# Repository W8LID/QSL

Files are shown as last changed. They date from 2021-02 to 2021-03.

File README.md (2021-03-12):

# QSL
A PCB QSL card that can be used as a cross band repeater.

QSL_V3

Introduction

The PCB QSL is a spin on the QSL cards that amateur radio operatrors send to one another to confirm contacts they have made over the air. QSL cards resemble post cards but also have information detailing the contact(s) made between two amateur radio operators.  QSL cards are also similar to post cards in that they often have artwork that can represent where or who they came from.

While first trying out KiCad, I came up with the idea that a PCB would make an interesting card that represents my interests in radio, electronics and micro controllers. The PCB QSL has all of the standard features of a paper QSL with silkscreened fields to fill out with contact info. It is also an unpopulated PCB that can be assembled into a working crossband reapeater.

The main components are an Atmel ATMEGA328 and Doji DRA818 VHF and UHF modules. The ATMEGA328 handles the module I/O and serial communications to configure the modules. A small number of passive components are also required to get up and running.

The Circuit

The original version (black solder mask) can only be assembled into a crossband repeater. Later versions can be used as a repeater, the default configuration, or as a dual band 2m, 70cm FM transceiver. In either configuration the goal was to use the minimum number of components as possible. 

In crossband, the audio out and in from each Dorji module are cross connected. This provides a simple voice repeating functionality. 

I/O control for the modules allows for monitoring the squelch status and can key the PTT of an opposing module. The enabling (PD) and the high and low power level of the modules can be handled by the MCU.

While attempting to keep component count to a minimum, it was decided to use the intrnal oscillator on the ATMEGA328. There are no critical timing needs that require the need for an external oscillator. 

Provisions are made for adding headers for ICSP and FTDI programmers to flash a bootloader and program using the Arduino IDE as if it were any other Arduino dev board.

The RF output of the modules are fed to a low pass filter before ending up at u.FL connectors. 

The dual band transceiver option is currently considered experimental and should be treated as such, feel free to offer feedback.

Programming

I have started sending out cards that are already populated with the MCU and the minimum passives required to make a crossband reapeater, the only components required are the DRA818 V and U modules. On these the ATmega328 has already had the bootloader flashed to them. They have also had the basic sketch that is in this repo uploaded to them to verify the bootloader works. I have also moved away from the breadboard board configuration and have moved to MiniCore instead. It is a an improved solution. Instructions for installing MiniCore with the Arduino IDE can be found here https://github.com/MCUdude/MiniCore#how-to-install

Once installed just configure for the proper hardware. Select Tools > Board > MiniCore > ATmega328. Then select Tools > Clock > Internal 8MHz.

Some cards are equipped with the ATmega328PB. Select the variant that matches the chip on your QSL with Tools > Variant.

From there you can upload your own sketches from the Arduino IDE using the FTDI header J3.

A very simple crossband sketch is provided in this repo. It is setup for 145.725MHz input and 434.00MHz output, these are set by the variables named uplink and downlink. Be sure to check your local bandplan to ensure you’re opertaing in the correct portions of the bands. In all cases, please avoid 145.800-146.000MHz and 435.000-438.000MHz as these are internationally recognized satellite bands. DO NOT underestimate the ability of 0.5-1W of power being able to cause interference to satellites. It should also be noted that other weak signal portions of the bands should be avoided.

The provided sketch is very simple and is intended to show how the modules are configured using AT commands. Pin definitions are there to provide an example of what functions are designed for each GPIO. The main loop is very simple in that it reads the squelch pin status on the input module and keys the output module when a signal is detected.

Programming Issues and Other Considerations

As with other Arduino style boards you will get an error if anything is connected to the hardware UART when attempting to upload a sketch. On the PCB QSL we have the VHF module connected to the hardware UART. There are two options to avoid issues here. You can upload your sketch before soldering your module onto the board. You can also utilize the solderable jumper pads JP5 and JP6. Simply cut the small trace inside the pads to program then use a small bit of solder to reconnect after uploading. There is a possibility this might change on future by using SoftwareSerial for both modules.

The DRA818 datasheet lists the transmit current of the modules is 400mA in low power mode and 700mA in high power. Make sure the power supply you’re using is capable of supplying enough current safely. My FTDI programmer works well enough to transmit in low power mode but your mileage may vary.

There are no other known issues at this time.

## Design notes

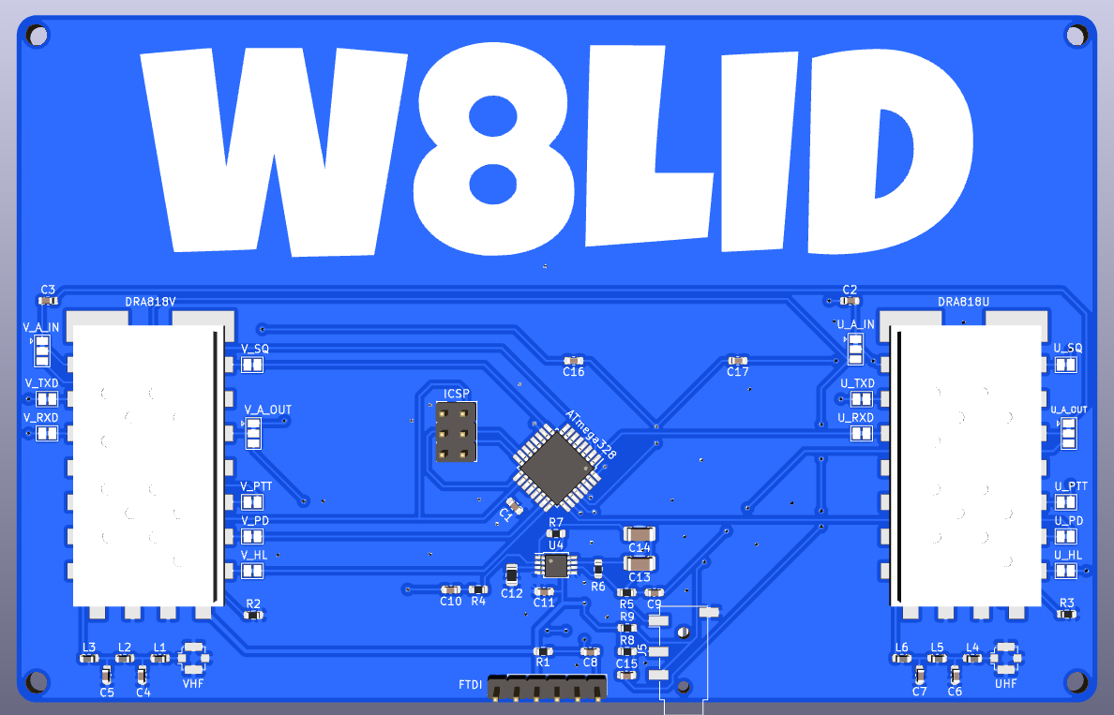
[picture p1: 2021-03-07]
QSL_V3.png

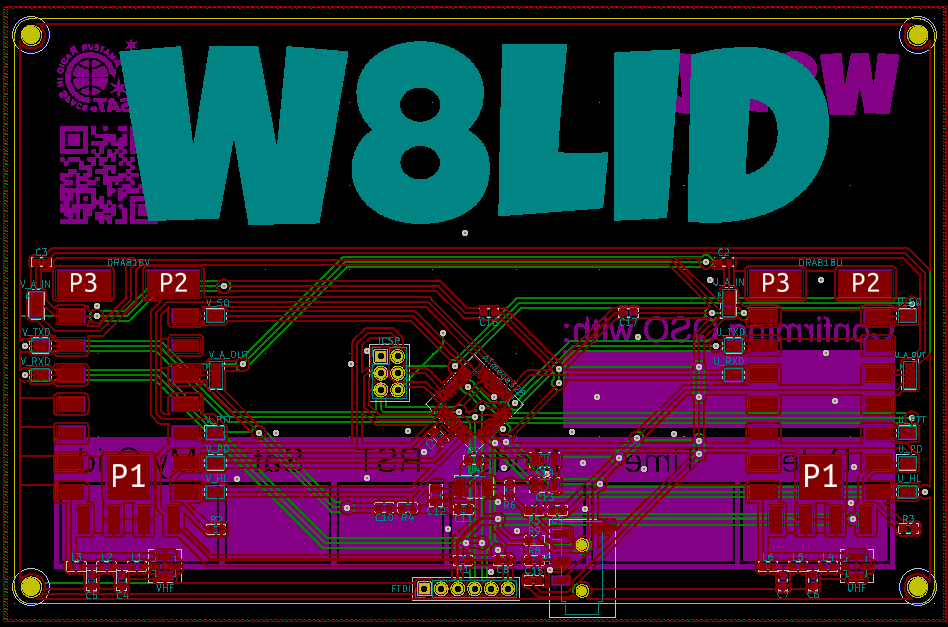
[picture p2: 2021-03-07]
QSL_V3_PCB.png

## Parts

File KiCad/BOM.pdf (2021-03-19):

Sheet1

Referance | Value | Footprint | LCSC P/N | Digi-Key P/N
L1, L3 | 56nH | 0603 | C316308
L2 | 97nH (100nH) | 0603 | | 445-6386-1-ND
L4, L6 | 18nH | 0603 | C316321
L5 | 31nH (30nH) | 0603 | | 490-6883-1-ND
C1,8 | 100nF | 0603 | C42998
C2,3 | 0.47uF | 0603 | C106851
C4,5 | 27pF | 0603 | C342893
C6,7 | 8.7pF | 0603 | C501848 (8.5pF) | 399-16269-1-ND
R1,2,3 | 10k | 0603 | C269701
J1,2 | u.FL | | C88374
U1 | ATMEGA328P-AU | TQFP-32 | ATMEGA328P-AU-ND
U2 | DRA818V
U3 | DRA818U

Below are optional/experimental
C9,10,16,17 0.47uF | 0603 | C106851
C11 | 1uF | 0603 | C26413
C12 | 4.7uF | 0805 | C50696
C13,14 | 100uF | 1206 | C77085
C15 | 100nF | 0603 | C42998
R4,5,6,7 | 20k | 0603 | C163880
R8,9 | 10k | 0603 | C269701
U4 | LM4810 | TSSOP-8

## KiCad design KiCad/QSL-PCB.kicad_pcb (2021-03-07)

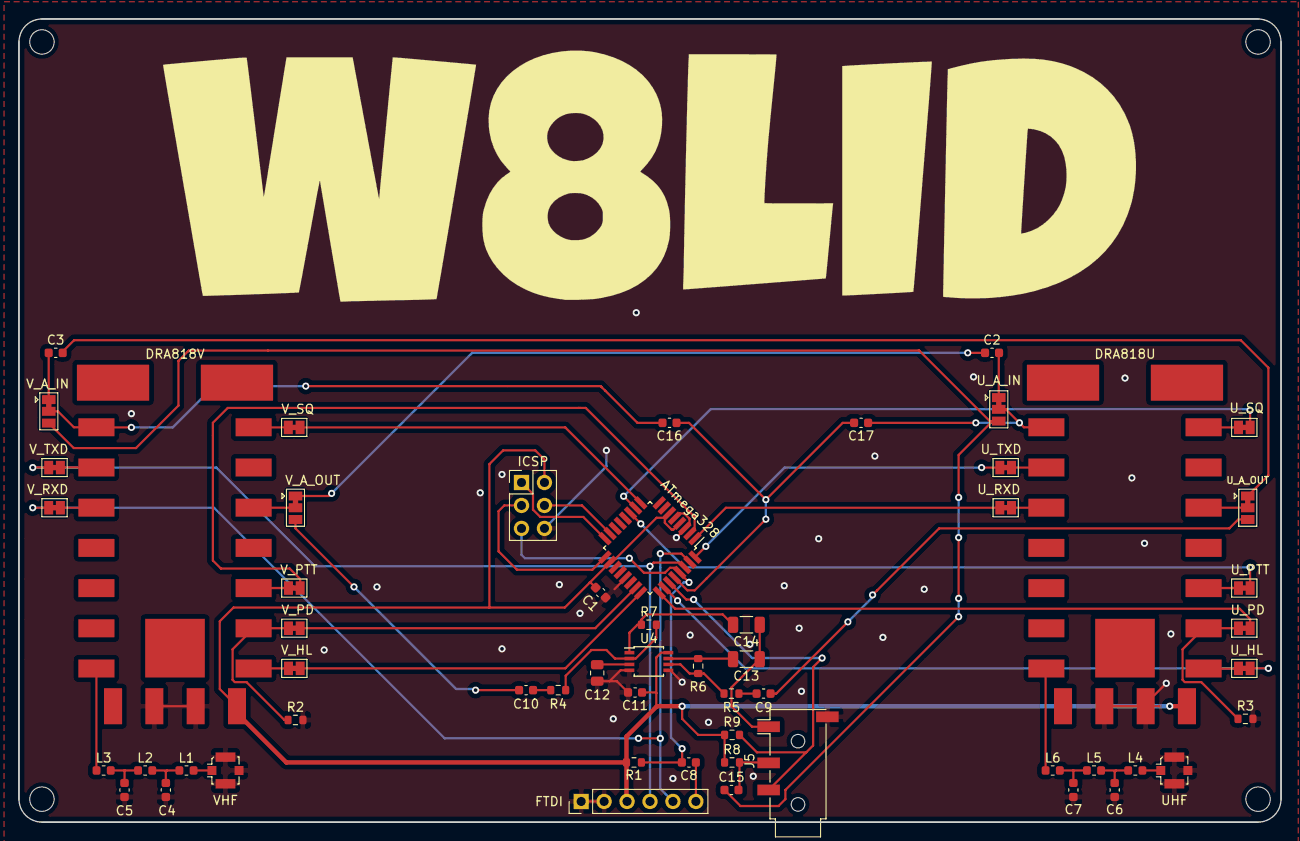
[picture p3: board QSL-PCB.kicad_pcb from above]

Board: 2 copper layers, 139.7 x 88.9 mm, 57 parts (0 on the bottom side), 61 nets.

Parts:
ATmega328: ATmega328P-AU; TQFP-32_7x7mm_P0.8mm
C1, C8, C15: 100nF; C_0603_1608Metric
C2, C3, C9, C10, C16, C17: 0.47uF; C_0603_1608Metric
C4, C5: 27pF; C_0603_1608Metric
C6, C7: 8.7pF; C_0603_1608Metric
C11: 1uF; C_0603_1608Metric
C12: 4.7uF; R_0805_2012Metric
C13, C14: 100uF; C_1206_3216Metric
FTDI: FTDI; PinHeader_1x06_P2.54mm_Vertical
ICSP: Conn_02x03_Odd_Even; PinHeader_2x03_P2.54mm_Vertical
J5: AudioJack4; Jack_3.5mm_PJ320D_Horizontal
L1, L3: 56nH; L_0603_1608Metric
L2: 100nH; L_0603_1608Metric
L4, L6: 18nH; L_0603_1608Metric
L5: 30nH; L_0603_1608Metric
R1, R2, R3: 10k; R_0603_1608Metric
R4, R5, R6, R7: 20k; R_0603_1608Metric
R8, R9: 10K; R_0603_1608Metric
U2: DRA818V; DRA818
U3: DRA818U; DRA818
U4: LM4810; TSSOP-8_3x3mm_P0.65mm
UHF: UHF; U.FL_Molex_MCRF_73412-0110_Vertical
U_A_IN: SolderJumper_3_Bridged12; SolderJumper-3_P1.3mm_Bridged12_Pad1.0x1.5mm
U_A_OUT: SolderJumper_3_Bridged12; SolderJumper-3_P1.3mm_Bridged12_Pad1.0x1.5mm
U_HL: Jumper; SolderJumper-2_P1.3mm_Bridged_Pad1.0x1.5mm
U_PD: Jumper; SolderJumper-2_P1.3mm_Bridged_Pad1.0x1.5mm
U_PTT: Jumper; SolderJumper-2_P1.3mm_Bridged_Pad1.0x1.5mm
U_RXD: Jumper; SolderJumper-2_P1.3mm_Bridged_Pad1.0x1.5mm
U_SQ: Jumper; SolderJumper-2_P1.3mm_Bridged_Pad1.0x1.5mm
U_TXD: Jumper; SolderJumper-2_P1.3mm_Bridged_Pad1.0x1.5mm
VHF: VHF; U.FL_Molex_MCRF_73412-0110_Vertical
V_A_IN: SolderJumper_3_Bridged12; SolderJumper-3_P1.3mm_Bridged12_Pad1.0x1.5mm
V_A_OUT: SolderJumper_3_Bridged12; SolderJumper-3_P1.3mm_Bridged12_Pad1.0x1.5mm
V_HL: Jumper; SolderJumper-2_P1.3mm_Bridged_Pad1.0x1.5mm
V_PD: Jumper; SolderJumper-2_P1.3mm_Bridged_Pad1.0x1.5mm
V_PTT: Jumper; SolderJumper-2_P1.3mm_Bridged_Pad1.0x1.5mm
V_RXD: Jumper; SolderJumper-2_P1.3mm_Bridged_Pad1.0x1.5mm
V_SQ: Jumper; SolderJumper-2_P1.3mm_Bridged_Pad1.0x1.5mm
V_TXD: Jumper; SolderJumper-2_P1.3mm_Bridged_Pad1.0x1.5mm

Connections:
GND: ATmega328.3, ATmega328.5, ATmega328.21, C1.2, C4.2, C5.2, C6.2, C7.2, C11.2, C12.2, FTDI.1, FTDI.2, ICSP.6, J5.S, R2.2, R3.2, U2.9, U2.10, U3.9, U3.10, U4.4, U4.5, UHF.2, VHF.2
unnamed: C2.1, V_A_OUT.1
unnamed: C2.2, U_A_IN.1
unnamed: C3.1, V_A_IN.1
unnamed: C3.2, U_A_OUT.1
unnamed: C4.1, L1.2, L2.1
unnamed: C5.1, L2.2, L3.1
unnamed: C6.1, L4.2, L5.1
unnamed: C7.1, L5.2, L6.1
unnamed: C8.1, FTDI.6
unnamed: ATmega328.29, C8.2, ICSP.5, R1.2
unnamed: C9.1, R5.2
unnamed: C9.2, U_A_OUT.3
unnamed: C10.1, V_A_OUT.3
unnamed: C10.2, R4.1
unnamed: C12.1, U4.3
unnamed: C13.1, C14.1, J5.T
unnamed: C13.2, R6.1, U4.7
unnamed: C14.2, R7.1, U4.1
unnamed: C15.1, U_A_IN.3, V_A_IN.3
unnamed: C15.2, J5.R1, R8.2
unnamed: ATmega328.28, C16.1, C17.2
unnamed: C16.2, U2.18, V_A_IN.2
unnamed: C17.1, U3.18, U_A_IN.2
unnamed: ATmega328.30, FTDI.4, V_TXD.1
unnamed: ATmega328.31, FTDI.5, V_RXD.1
unnamed: ATmega328.16, ICSP.1
unnamed: ATmega328.17, ICSP.3
unnamed: ATmega328.15, ICSP.4
unnamed: ATmega328.27, J5.R2, R9.2
unnamed: L1.1, VHF.1
unnamed: L3.2, U2.12
unnamed: L4.1, UHF.1
unnamed: L6.2, U3.12
unnamed: R2.1, U2.6, V_PD.2
unnamed: R3.1, U3.6, U_PD.2
unnamed: R4.2, R7.2, U4.2
unnamed: R5.1, R6.2, U4.6
unnamed: ATmega328.1, U_RXD.1
unnamed: ATmega328.2, V_PTT.1
unnamed: ATmega328.9, V_SQ.1
unnamed: ATmega328.10, U_SQ.1
unnamed: ATmega328.11, U_PTT.1
unnamed: ATmega328.23, V_PD.1
unnamed: ATmega328.24, V_HL.1
unnamed: ATmega328.25, U_PD.1
unnamed: ATmega328.26, U_HL.1
unnamed: ATmega328.32, U_TXD.1
unnamed: U2.1, V_SQ.2
unnamed: U2.3, V_A_OUT.2
unnamed: U2.5, V_PTT.2
unnamed: U2.7, V_HL.2
unnamed: U2.16, V_RXD.2
unnamed: U2.17, V_TXD.2
unnamed: U3.1, U_SQ.2
unnamed: U3.3, U_A_OUT.2
unnamed: U3.5, U_PTT.2
unnamed: U3.7, U_HL.2
unnamed: U3.16, U_RXD.2
unnamed: U3.17, U_TXD.2
VCC: ATmega328.4, ATmega328.6, ATmega328.18, C1.1, C11.1, FTDI.3, ICSP.2, R1.1, R8.1, R9.1, U2.8, U3.8, U4.8

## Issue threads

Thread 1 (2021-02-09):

8.7pF Capacitor in BOM is wrong

supercazzola, 2021-02-09:
I believe Digi-Key part number 399-16269-1-ND is a better match for the 8.7pF capacitors. The one listed was not a  0603 form factor.

W8LID, 2021-03-21:
Corrected Digi-Key part number and also added a comparable part from LCSC.

Closed 2021-03-21.

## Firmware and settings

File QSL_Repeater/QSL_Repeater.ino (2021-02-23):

#include <SoftwareSerial.h>

// Pin definitions
#define V_PD A0
#define V_HL A1
#define U_PD A2
#define U_HL A3
#define V_TXD 1 //V TXD and RXD are redundant, handled by Serial()
#define V_RXD 0 //
#define U_TXD 2
#define U_RXD 3
#define V_PTT 4
#define V_SQ 5
#define U_SQ 6
#define U_PTT 7

// bandwith in KHz ( 0= 12.5KHz or 1= 25KHz )
int bw = 1;

// squelch level  ( 0 - 8 ); 0 = "open" 
int squ = 1;

// rx frequency in MHz
float uplink = 145.7250;

// tx frequency in MHz
float downlink = 434.0000;

// 67.0Hz PL
String plTone = "0001";

//UHF Serial
SoftwareSerial U_Serial(U_TXD, U_RXD); // RX, TX

void setup()
{
  //Setup pins
  pinMode(V_PD, OUTPUT);
  pinMode(V_HL, OUTPUT);
  pinMode(U_PD, OUTPUT);
  pinMode(U_HL, OUTPUT);
  pinMode(V_PTT, OUTPUT);
  pinMode(U_PTT, OUTPUT);
  pinMode(V_SQ, INPUT);
  pinMode(U_SQ, INPUT);

  //Keep modules in powerdown initially during setup
  digitalWrite(V_PD, LOW);
  digitalWrite(U_PD, LOW);

  //Put modules in low power (0.5w) mode
  digitalWrite(V_HL, LOW);
  digitalWrite(U_HL, LOW);

  //Put modules in RX
  digitalWrite(V_PTT, HIGH);
  digitalWrite(U_PTT, HIGH);

  //Setup serial ports
  Serial.begin(9600);
  U_Serial.begin(9600);

  //Powerup modules
  digitalWrite(V_PD, HIGH);
  digitalWrite(U_PD, HIGH);

  //Give some delay for modules to initialize
  delay(100);

  //Configure the modules
  configureModules();
}

void loop()
{
  // put your main code here, to run repeatedly:
  bool vSQSense = digitalRead(V_SQ);

  if(!vSQSense)
  {
    digitalWrite(U_PTT, LOW);
  }
  else
  {
    digitalWrite(U_PTT, HIGH);
  }
}

void configureModules()
{
  // Uplink
    delay(100);
    Serial.print("AT+DMOSETGROUP=");
    Serial.print(bw,1);
    Serial.print(",");
    Serial.print(uplink,4); 
    Serial.print(",");
    Serial.print(uplink,4);
    Serial.print(",");
    Serial.print(plTone);
    Serial.print(",");
    Serial.print(squ);
    Serial.print(",");
    Serial.println(plTone);

    Serial.println("AT+DMOSETVOLUME=4");

    // Downlink
    delay(100);
    U_Serial.print("AT+DMOSETGROUP=");
    U_Serial.print(bw,1);
    U_Serial.print(",");
    U_Serial.print(downlink,4); 
    U_Serial.print(",");
    U_Serial.print(downlink,4);
    U_Serial.print(",");
    U_Serial.print("0000");
    U_Serial.print(",");
    U_Serial.print(squ);
    U_Serial.print(",");
    U_Serial.println("0000");
}

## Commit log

2020-12-22 Add PCB layout
    PCB outline layout.
2021-01-13 Initial BOM
    BOM PDF
2021-02-23 Board definition
    The breadboard Arduino with internal 8MHz clock is used for this board.
2021-03-07 Delete PCB_QSL.png
    delete to update images
2021-03-07 Delete BOM.pdf
    delete from here, going into KiCad folder
2021-03-07 Upload KiCad design files
    KiCad files
    [BOM.ods, QSL-PCB.kicad_pcb, QSL-PCB.sch]
2021-03-19 Update BOM
    Update BOM spreadsheet and add PDF version.
    [BOM.ods]
